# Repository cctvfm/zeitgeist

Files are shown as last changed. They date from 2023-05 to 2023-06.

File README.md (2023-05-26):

# zeitgeist
Zeitgeist is a design for a delay effect/sound source based around heavy abuse of a PT2399 karaoke delay chip devised by Rob Hordijk.

Eagle .sch and .brd provided, along with gerbers ready to go.
BOM included
Art Included
Tayda Enclosure Drill Template:
https://drill.taydakits.com/box-designs/new?public_key=bjFJdjJ0OW5hZGFLbC9yd1lEM01qQT09Cg==

This fits in a 1590BB2 enclosure. The jack and switch PCBs aren't strictly necessary if you don't mind doing some more wiring.

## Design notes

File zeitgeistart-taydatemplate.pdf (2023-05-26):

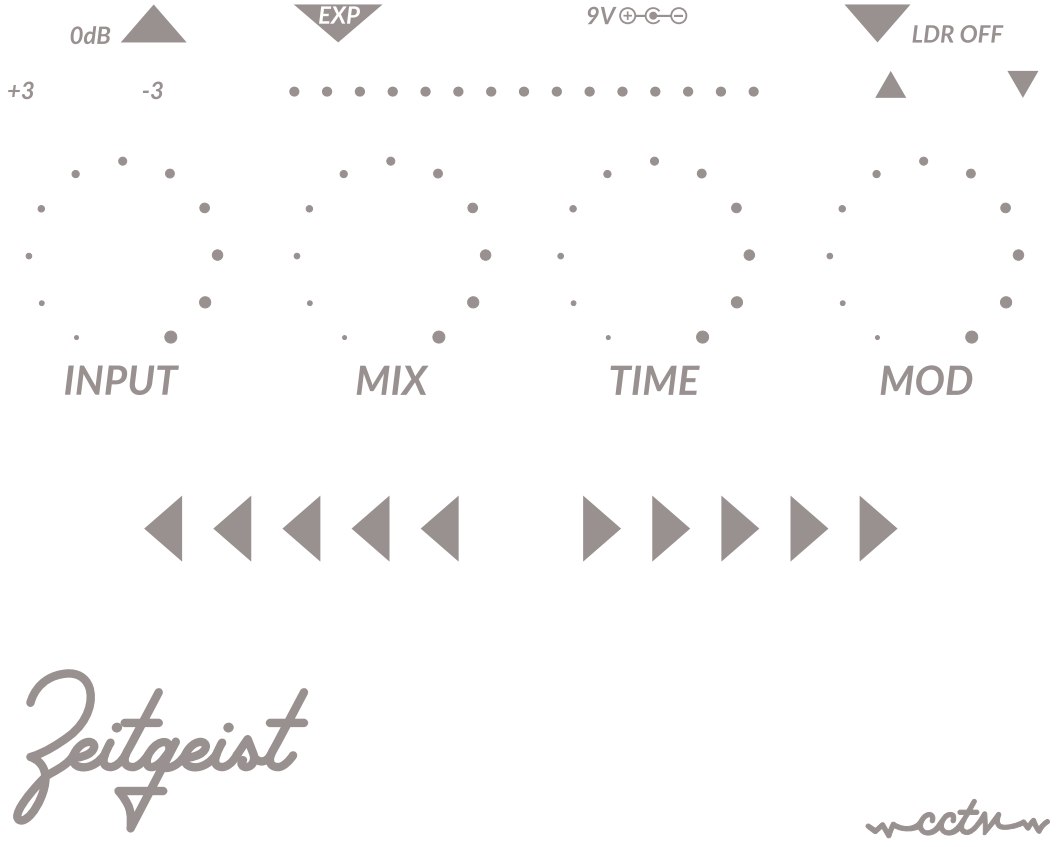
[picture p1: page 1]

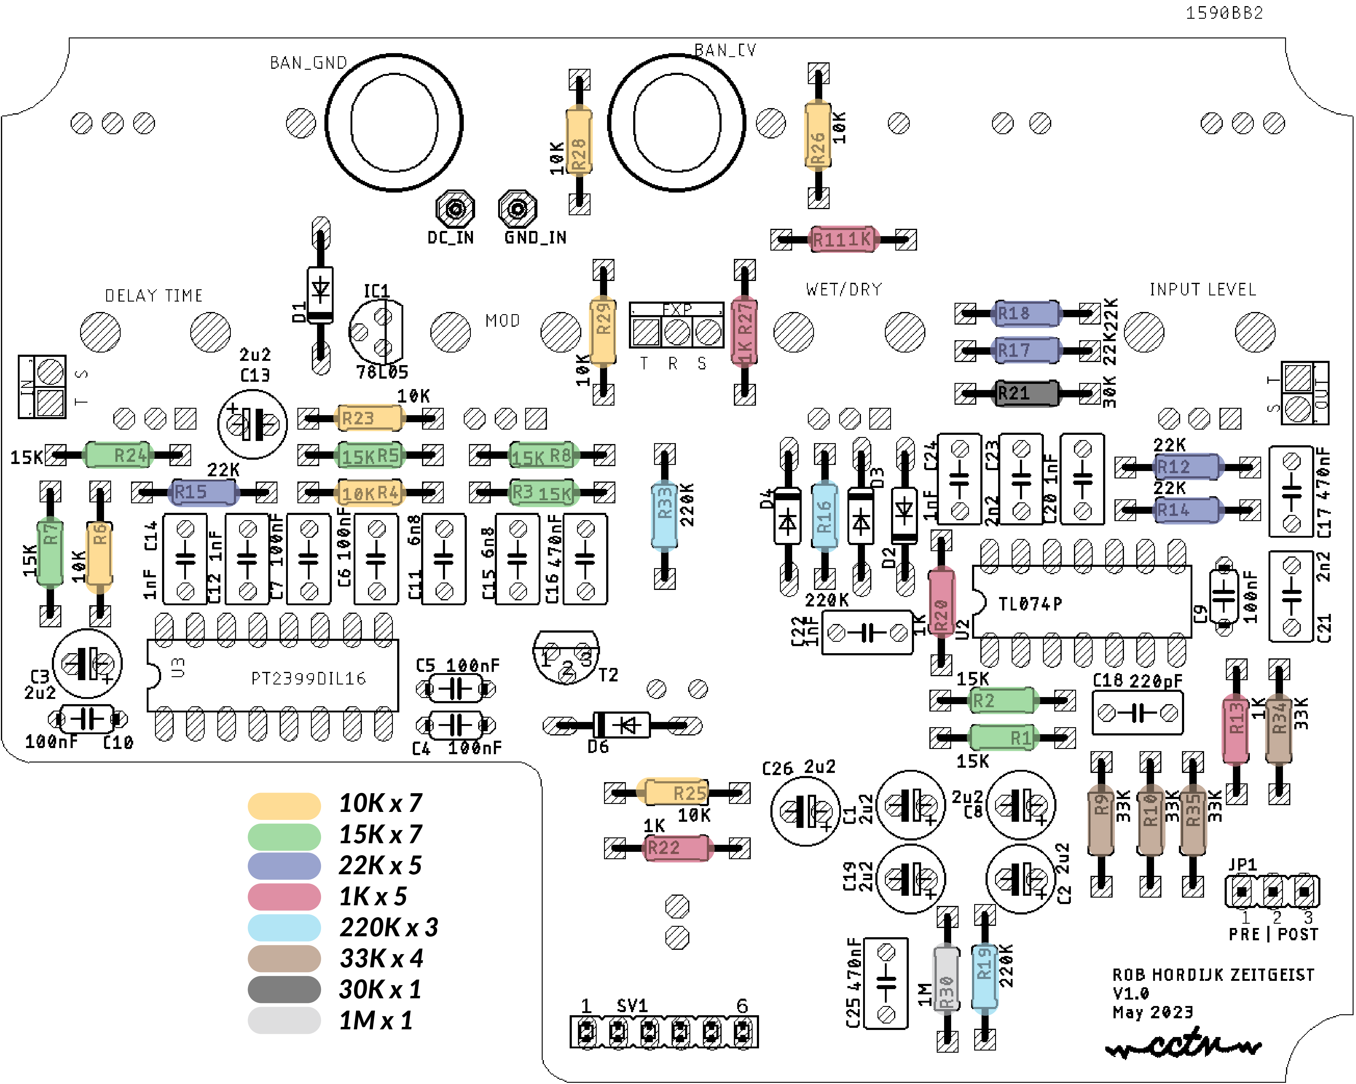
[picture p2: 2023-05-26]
colour-codedresistors.png

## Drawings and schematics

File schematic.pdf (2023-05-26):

1K ¹⁰K | 10K +5V | GND GND GNDSUBMINI_SPDT

A

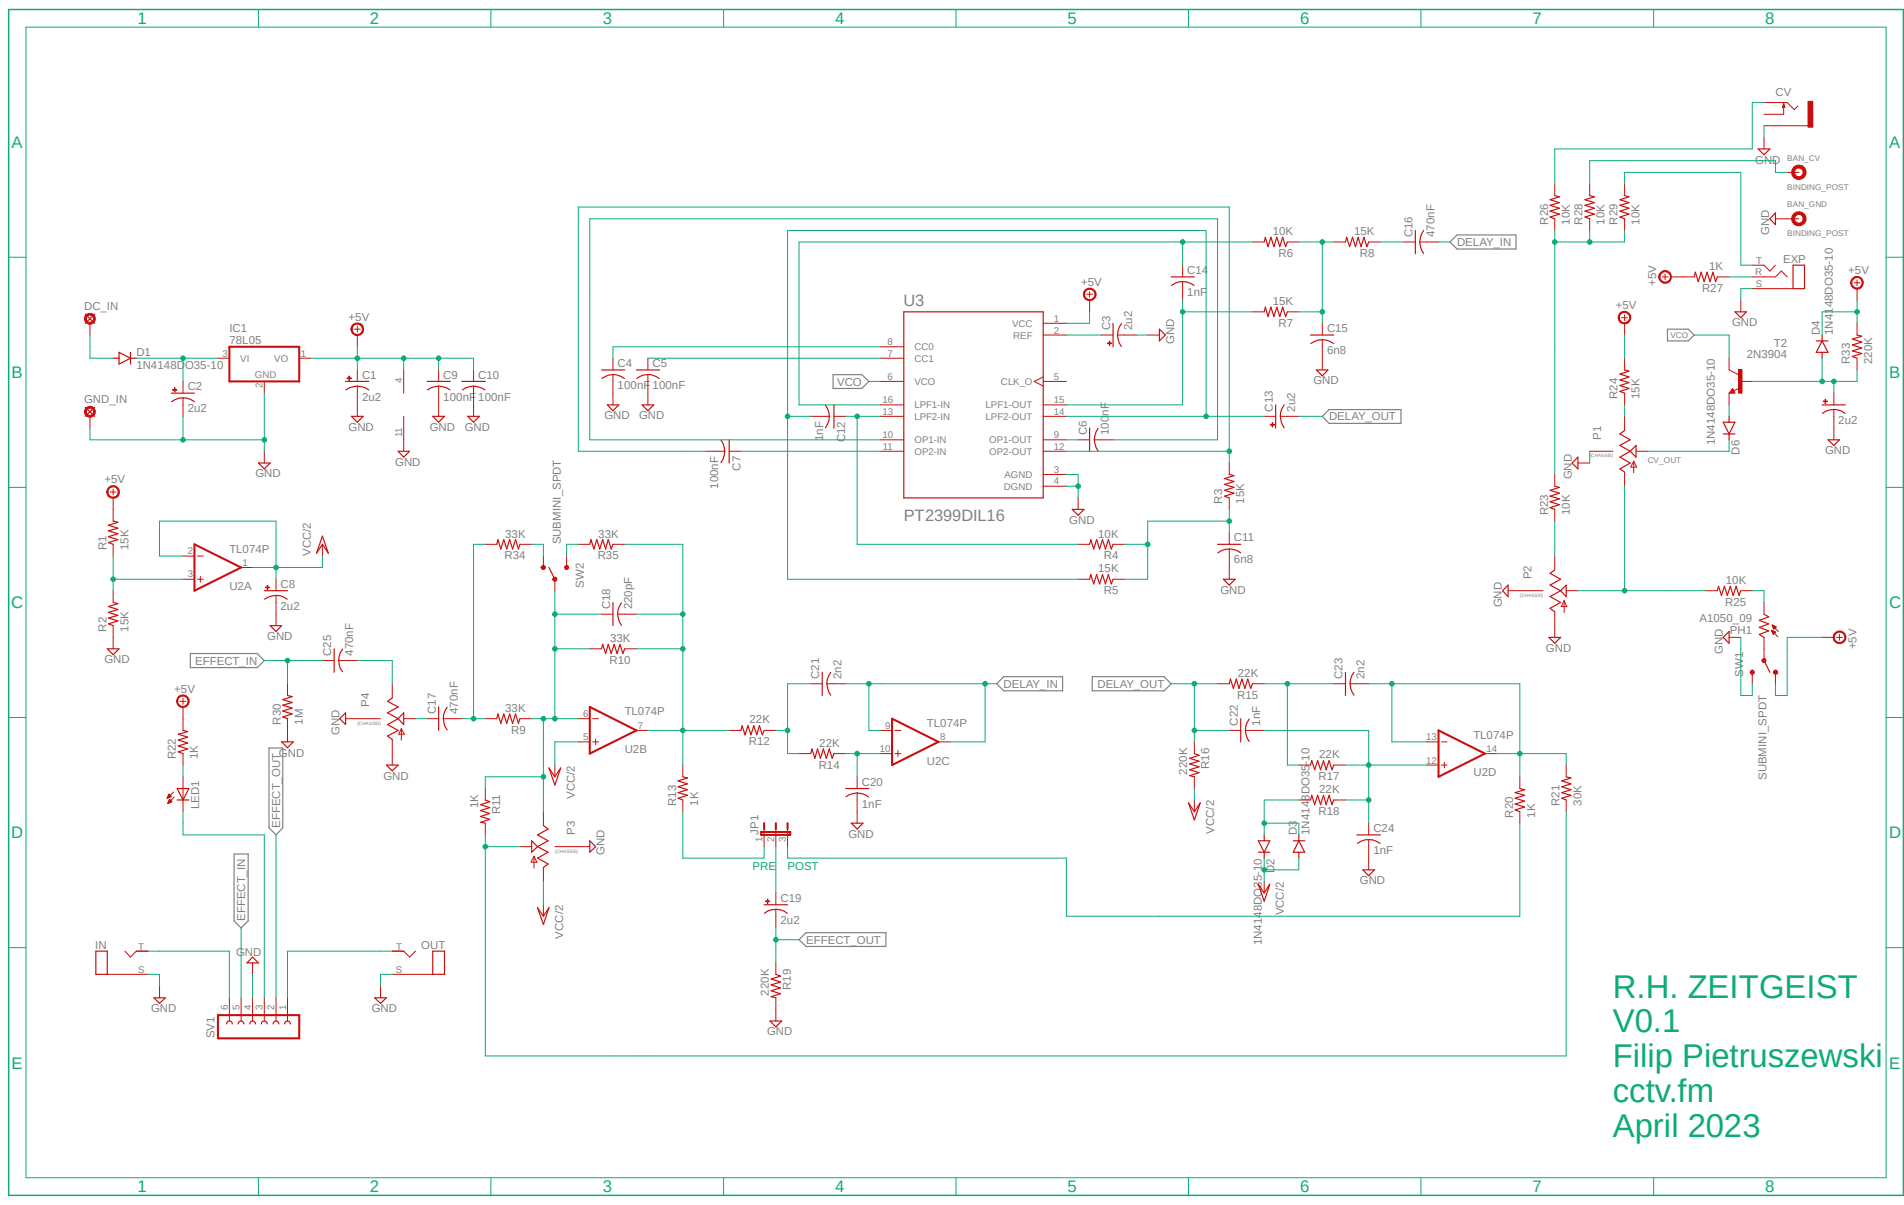
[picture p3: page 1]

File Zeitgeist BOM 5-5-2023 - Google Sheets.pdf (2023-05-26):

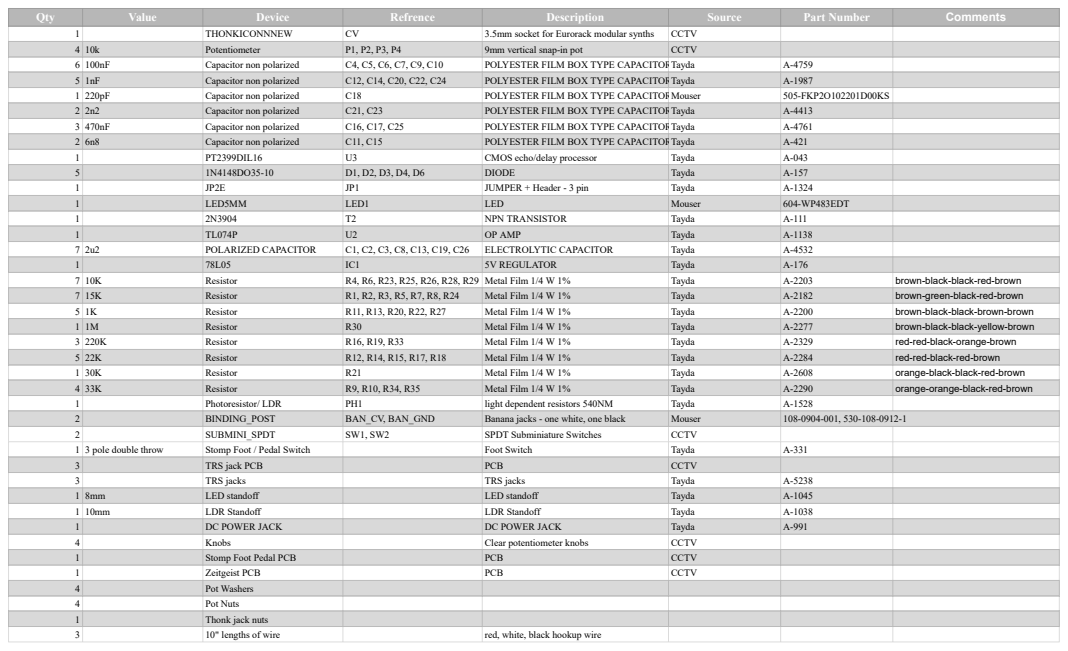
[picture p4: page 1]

POLYESTER FILM BOX TYPE CAPACITOR

brown-black-black-red-brown
brown-green-black-red-brown
brown-black-black-brown-brown
brown-black-black-yellow-brown
red-red-black-orange-brown
red-red-black-red-brown
orange-black-black-red-brown
orange-orange-black-red-brown

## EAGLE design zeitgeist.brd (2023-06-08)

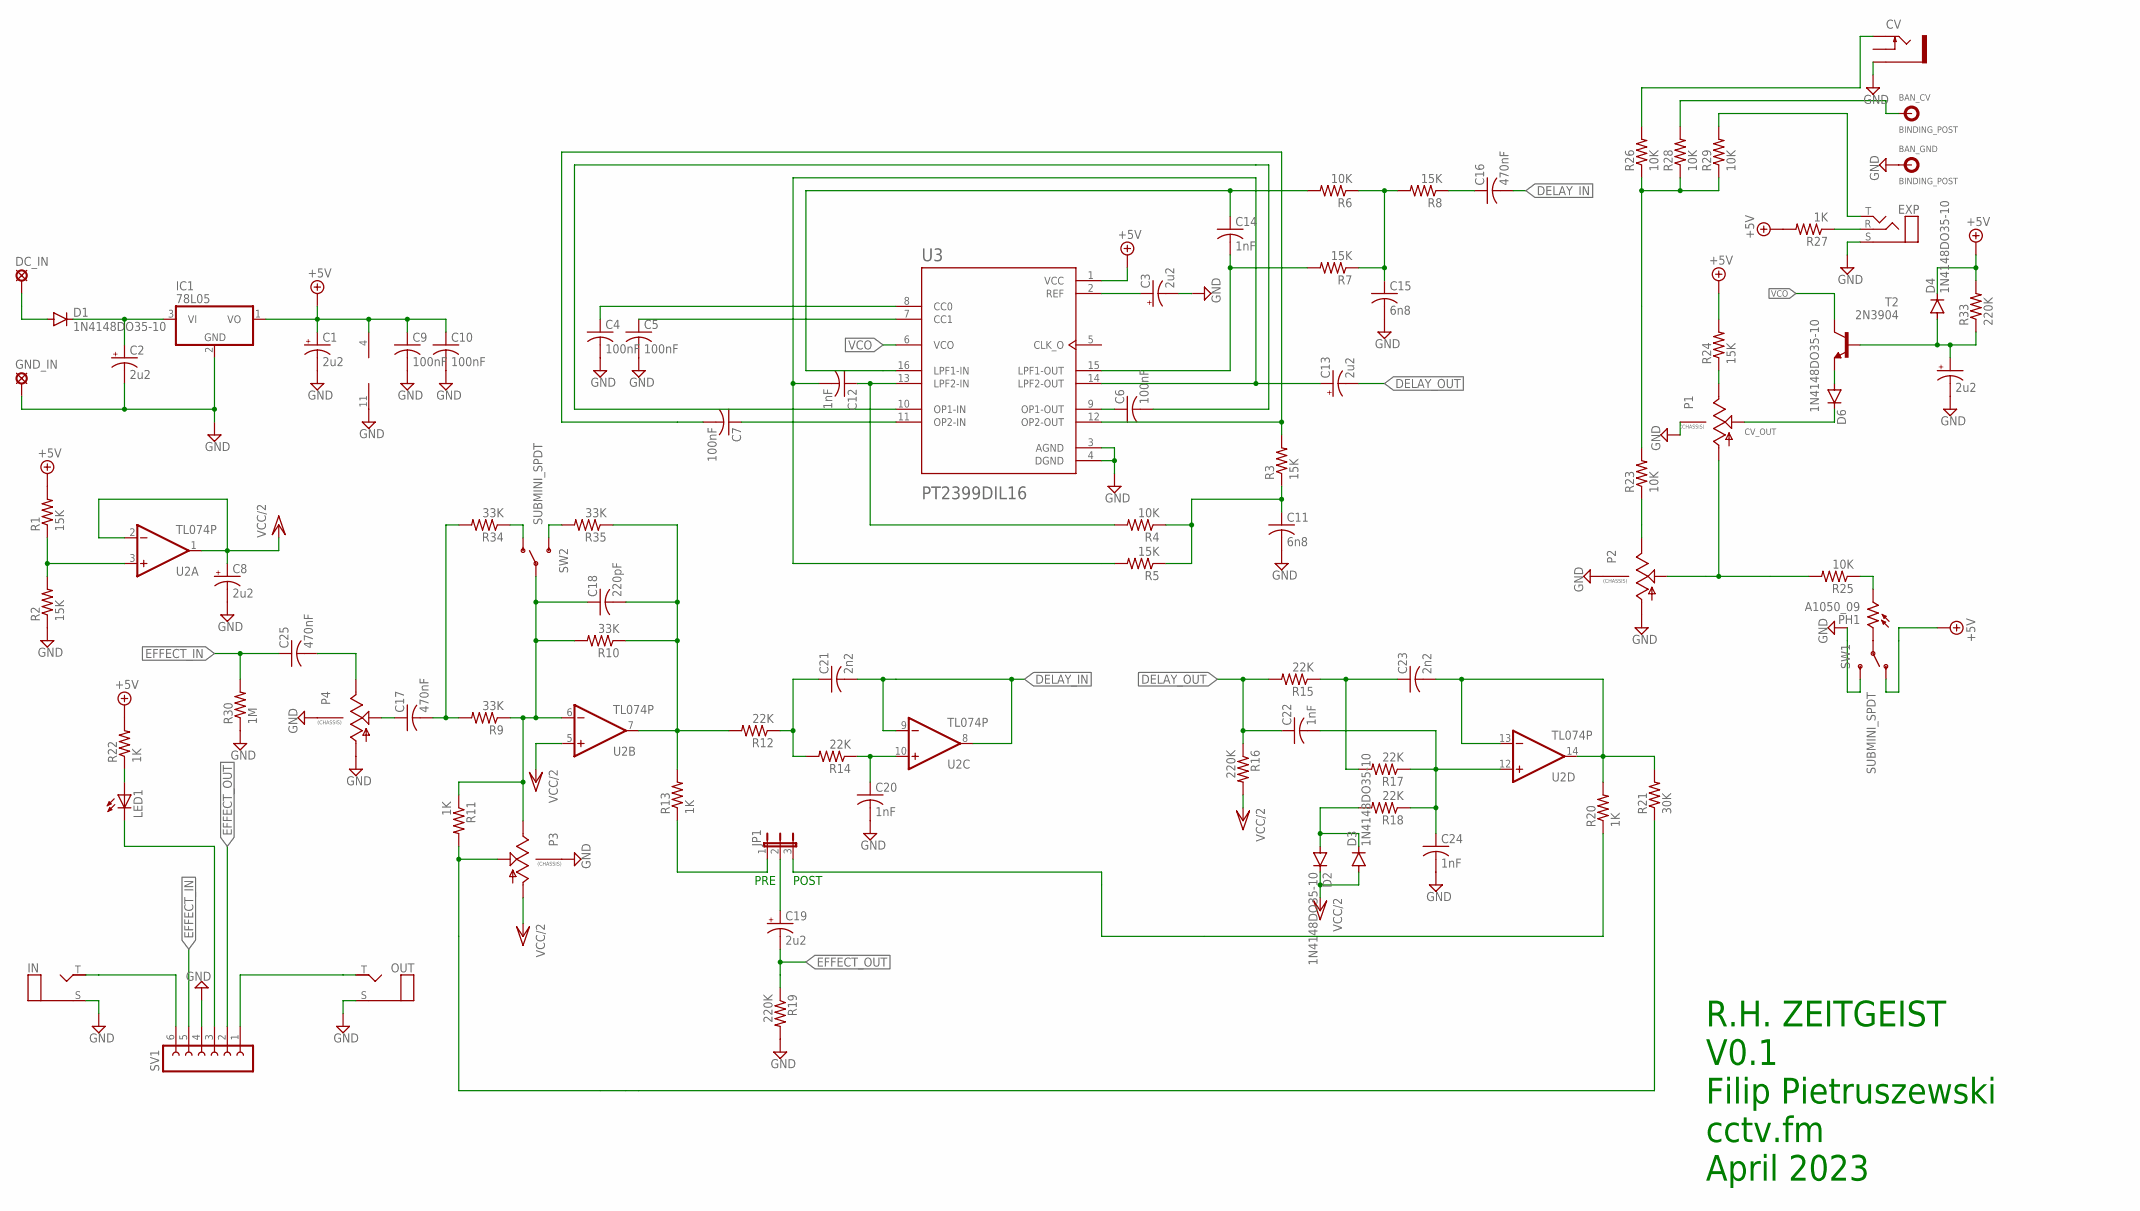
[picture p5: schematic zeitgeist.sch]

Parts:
BAN_CV: BINDING_POST
BAN_GND: BINDING_POST
C1, C2, C3, C8, C13, C19, C26: 2u2; E2,5-6
C4, C5, C9, C10: 100nF; C050-024X044
C6, C7: 100nF; C050-035X075
C11, C15: 6n8; C050-035X075
C12, C14, C20, C22, C24: 1nF; C050-035X075
C16, C17, C25: 470nF; C050-035X075
C18: 220pF; C050-035X075
C21, C23: 2n2; C050-035X075
CV: THONKICONNNEW; WQP-PJ301M-12_JACK
D1, D2, D3, D4, D6: 1N4148DO35-10; DO35-10
DC_IN: SE14
EXP: STEREO_PADS; 3PADS
GND_IN: SE14
IC1: 78L05; TO92
IN: MONO_PADS; 2PADS
JP1: JP2E; JP2
LED1: LED5MM
OUT: MONO_PADS; 2PADS
P1, P2, P3, P4: 9MM_SNAP-IN_POT_CHASSIS; 9MM_SNAP-IN_POT
PH1: A1050_09; T0-46-A10XX
R1, R2, R3, R5, R7, R8, R24: 15K; 0204/7
R4, R6, R23, R25, R26, R28, R29: 10K; 0204/7
R9, R10, R34, R35: 33K; 0204/7
R11, R13, R20, R22, R27: 1K; 0204/7
R12, R14, R15, R17, R18: 22K; 0204/7
R16, R19, R33: 220K; 0204/7
R21: 30K; 0204/7
R30: 1M; 0204/7
SV1: FE06-1; FE06
SW1, SW2: SUBMINI_SPDT; SUBMINI_TOGGLE
T2: 2N3904; TO92
U2: TL074P; DIL14
U3: PT2399DIL16; DIL16

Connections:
+5V: C1.+, C9.1, C10.1, D4.C, IC1.1 (VO), R1.2, R22.2, R24.2, R27.2, R33.2, SW1.1 (O), U2.4 (V+), U3.1 (VCC)
CV_IN: CV.P$1_TIP (TIP), R26.2
CV_OUT: D6.C, P1.2 (S)
DELAY_IN: C16.2, C21.2, U2.8 (OUT), U2.9 (-IN)
DELAY_OUT: C13.-, C22.1, R15.2, R16.1
EFFECT_IN: C25.1, R30.2, SV1.5
EFFECT_OUT: C19.-, R19.1, SV1.2
GND: BAN_GND.P$1, C1.-, C2.-, C3.-, C4.2, C5.2, C8.-, C9.2, C10.2, C11.2, C15.2, C20.2, C24.2, C26.-, CV.P$3_SLEEVE (SLEEVE), EXP.S, GND_IN.MP, IC1.2 (GND), IN.S, OUT.S, P1.CHASSIS1, P1.CHASSIS2, P2.1 (A), P2.CHASSIS1, P2.CHASSIS2, P3.CHASSIS1, P3.CHASSIS2, P4.1 (A), P4.CHASSIS1, P4.CHASSIS2, R2.1, R19.2, R30.1, SV1.4, SW1.3 (S), U2.11 (V-), U3.3 (AGND), U3.4 (DGND)
unnamed: C2.+, D1.C, IC1.3 (VI)
unnamed: C6.2, U3.10 (OP1-IN)
unnamed: C6.1, U3.9 (OP1-OUT)
unnamed: C7.1, U3.11 (OP2-IN)
unnamed: C3.+, U3.2 (REF)
unnamed: C7.2, R3.2, U3.12 (OP2-OUT)
unnamed: R1.1, R2.2, U2.3 (+IN)
unnamed: C5.1, U3.7 (CC1)
unnamed: C4.1, U3.8 (CC0)
unnamed: C11.1, R3.1, R4.1, R5.1
unnamed: C12.1, R4.2, U3.13 (LPF2-IN)
unnamed: C23.1, R15.1, R17.2
unnamed: C12.2, C13.+, R5.2, U3.14 (LPF2-OUT)
unnamed: C14.1, R6.2, U3.16 (LPF1-IN)
unnamed: C14.2, R7.2, U3.15 (LPF1-OUT)
unnamed: C15.1, R6.1, R7.1, R8.2
unnamed: C16.1, R8.1
unnamed: D1.A, DC_IN.MP
unnamed: C17.1, P4.2 (S)
unnamed: C18.1, P3.3 (E), R9.1, R10.2, R11.1, SW2.COM (COMMON), U2.6 (-IN)
unnamed: C17.2, R9.2, R34.2
unnamed: P3.2 (S), R11.2, R21.1
unnamed: C18.2, R10.1, R12.2, R13.2, R35.1, U2.7 (OUT)
unnamed: C19.+, JP1.2
unnamed: JP1.1, R13.1
unnamed: C21.1, R12.1, R14.2
unnamed: C20.1, R14.1, U2.10 (+IN)
unnamed: C22.2, C24.1, R17.1, R18.1, U2.12 (+IN)
unnamed: D2.A, D3.C, R18.2
unnamed: LED1.A, R22.1
unnamed: C23.2, R20.2, R21.2, U2.13 (-IN), U2.14 (OUT)
unnamed: P2.3 (E), R23.1
unnamed: JP1.3, R20.1
unnamed: P1.1 (A), P2.2 (S), R25.2
unnamed: P1.3 (E), R24.1
unnamed: D6.A, T2.3 (E)
unnamed: PH1.2, R25.1
unnamed: PH1.1, SW1.COM (COMMON)
unnamed: R23.2, R26.1, R28.1, R29.1
unnamed: EXP.R, R27.1
unnamed: LED1.K (C), SV1.3
unnamed: C25.2, P4.3 (E)
unnamed: IN.T, SV1.6
unnamed: EXP.T, R29.2
unnamed: BAN_CV.P$1, R28.2
unnamed: OUT.T, SV1.1
unnamed: R35.2, SW2.3 (S)
unnamed: R34.1, SW2.1 (O)
unnamed: C26.+, D4.A, R33.1, T2.2 (B)
VCC/2: C8.+, D2.C, D3.A, P3.1 (A), R16.2, U2.1 (OUT), U2.2 (-IN), U2.5 (+IN)
VCO: T2.1 (C), U3.6 (VCO)

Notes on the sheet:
R.H. ZEITGEIST V0.1 Filip Pietruszewski cctv.fm April 2023
PRE
POST

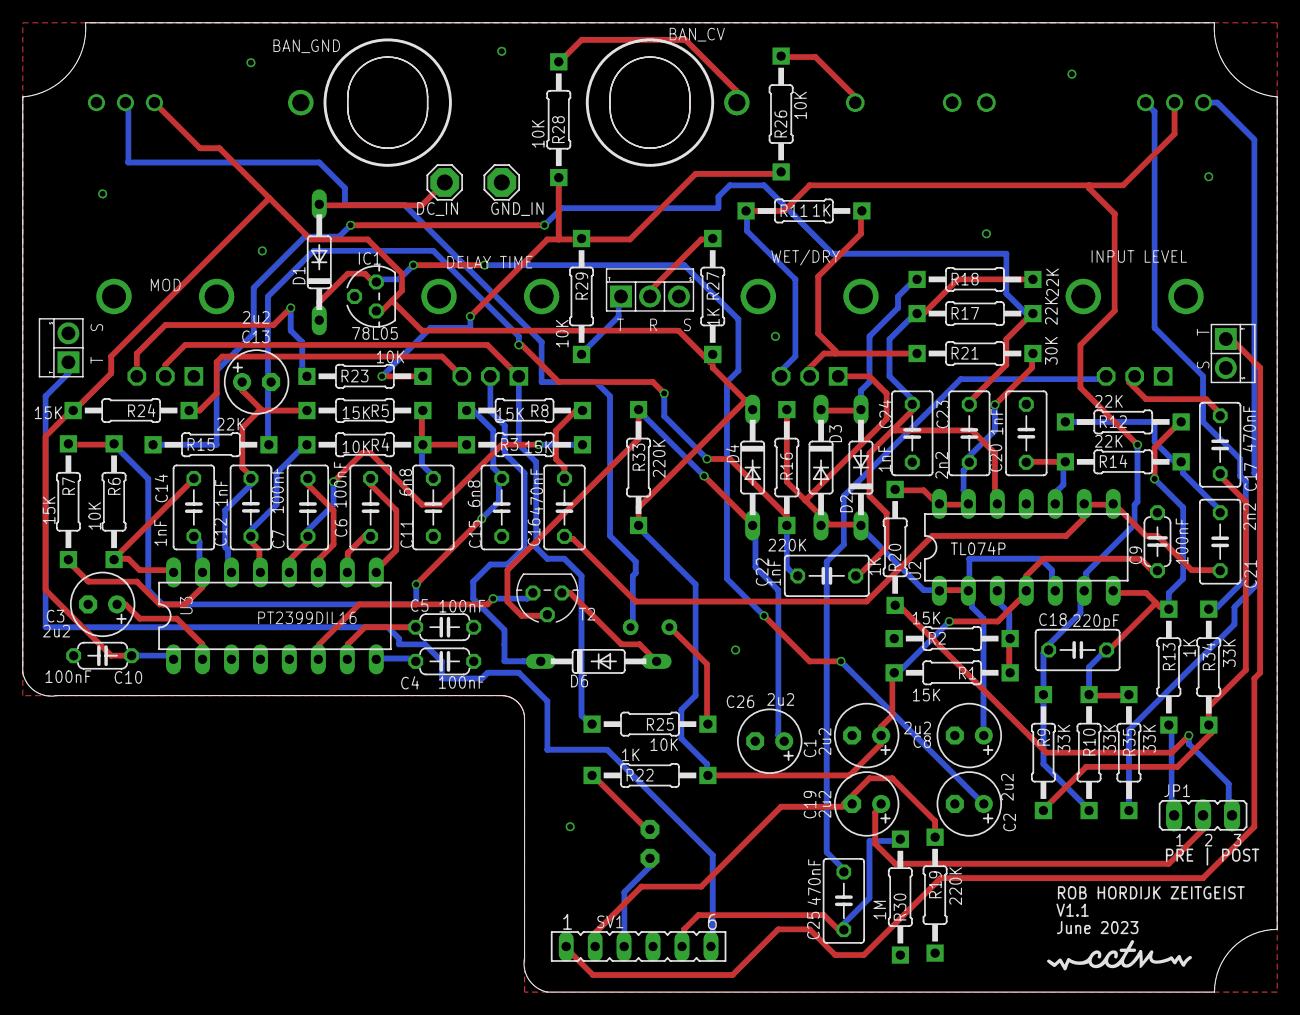
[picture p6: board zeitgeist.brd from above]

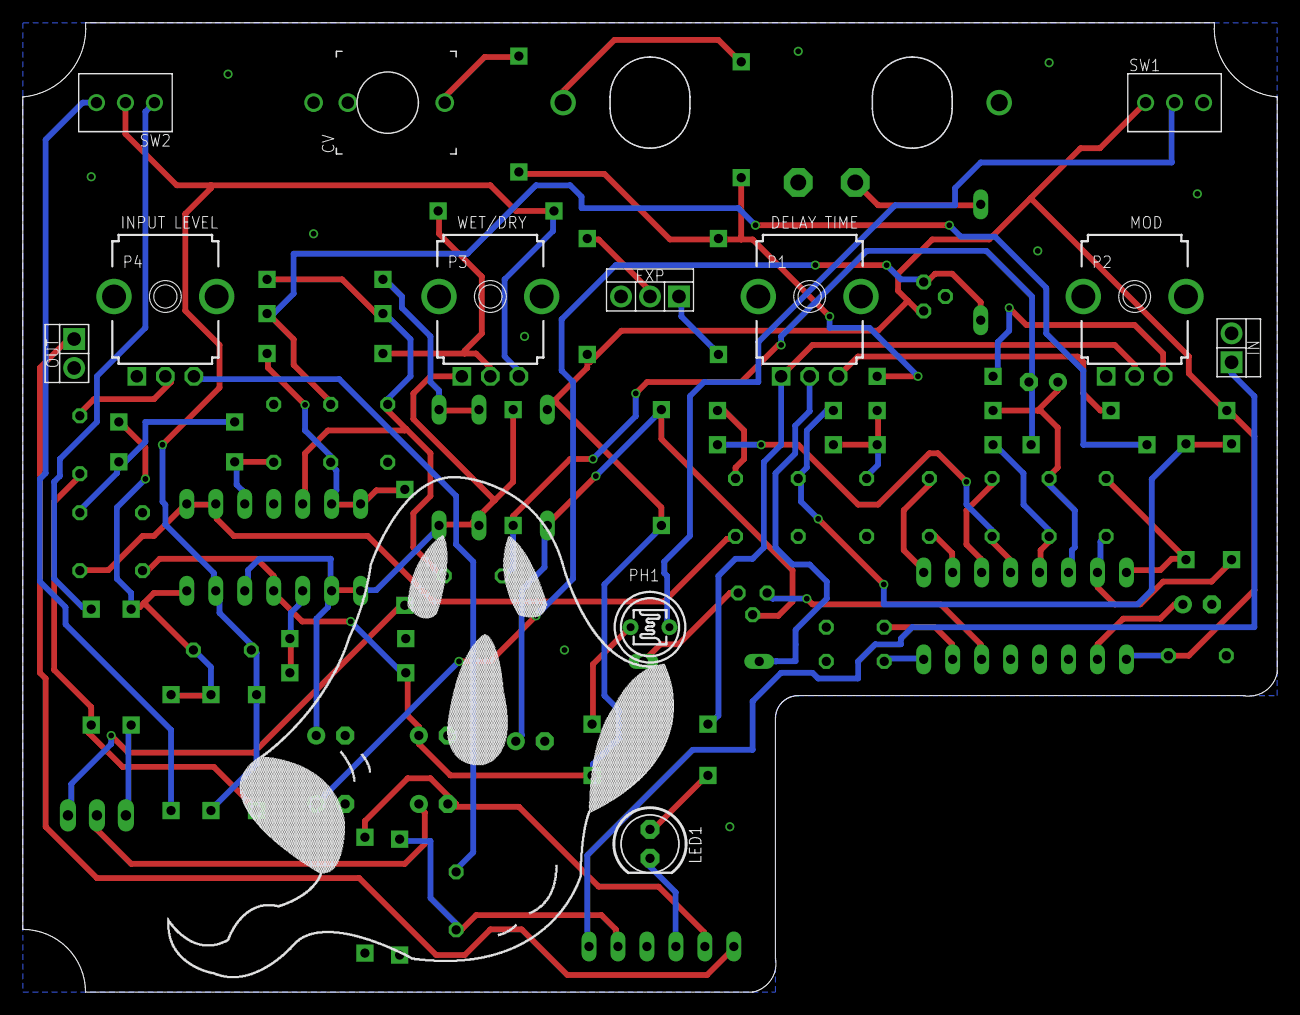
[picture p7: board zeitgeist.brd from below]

Board: 2 copper layers, 110.0 x 85.0 mm, 86 parts (9 on the bottom side), 59 nets.

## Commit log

2023-05-26 Added Initial files
    [zeitgeist.brd, zeitgeist.sch]
2023-05-26 Add files via upload
    Added 3pdt pcb and jackpack pcb
2023-05-26 Add files via upload
    Uploaded Schematic PDF
2023-06-08 Fixed reversed Time and Mod pots
    [zeitgeist.brd]

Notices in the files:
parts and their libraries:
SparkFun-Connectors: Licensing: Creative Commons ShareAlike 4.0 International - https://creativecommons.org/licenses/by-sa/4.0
